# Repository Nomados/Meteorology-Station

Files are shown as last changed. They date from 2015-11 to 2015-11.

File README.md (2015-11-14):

# Meteorology-Station
This device is based on stm32F051 MCU and features measurements of 
temperature, humidity and pressure. It uses sh1106 1.3 OLED display to 
show data and is capable to transfer data via two UARTs if you want to 
organize radio communication. It also has Eagle PCB layout and ready to 
use gerbers (SeedStudio format).

This application uses Chibios/RT RTOS (2.6.x) and uGFX graphics engine.
You should download this software. Place Chibios and uGFX in ../ folder 
of makefile's location. 

For more details please visit:
http://mcudu.blogspot.kr/2015/11/meteorology-station.html

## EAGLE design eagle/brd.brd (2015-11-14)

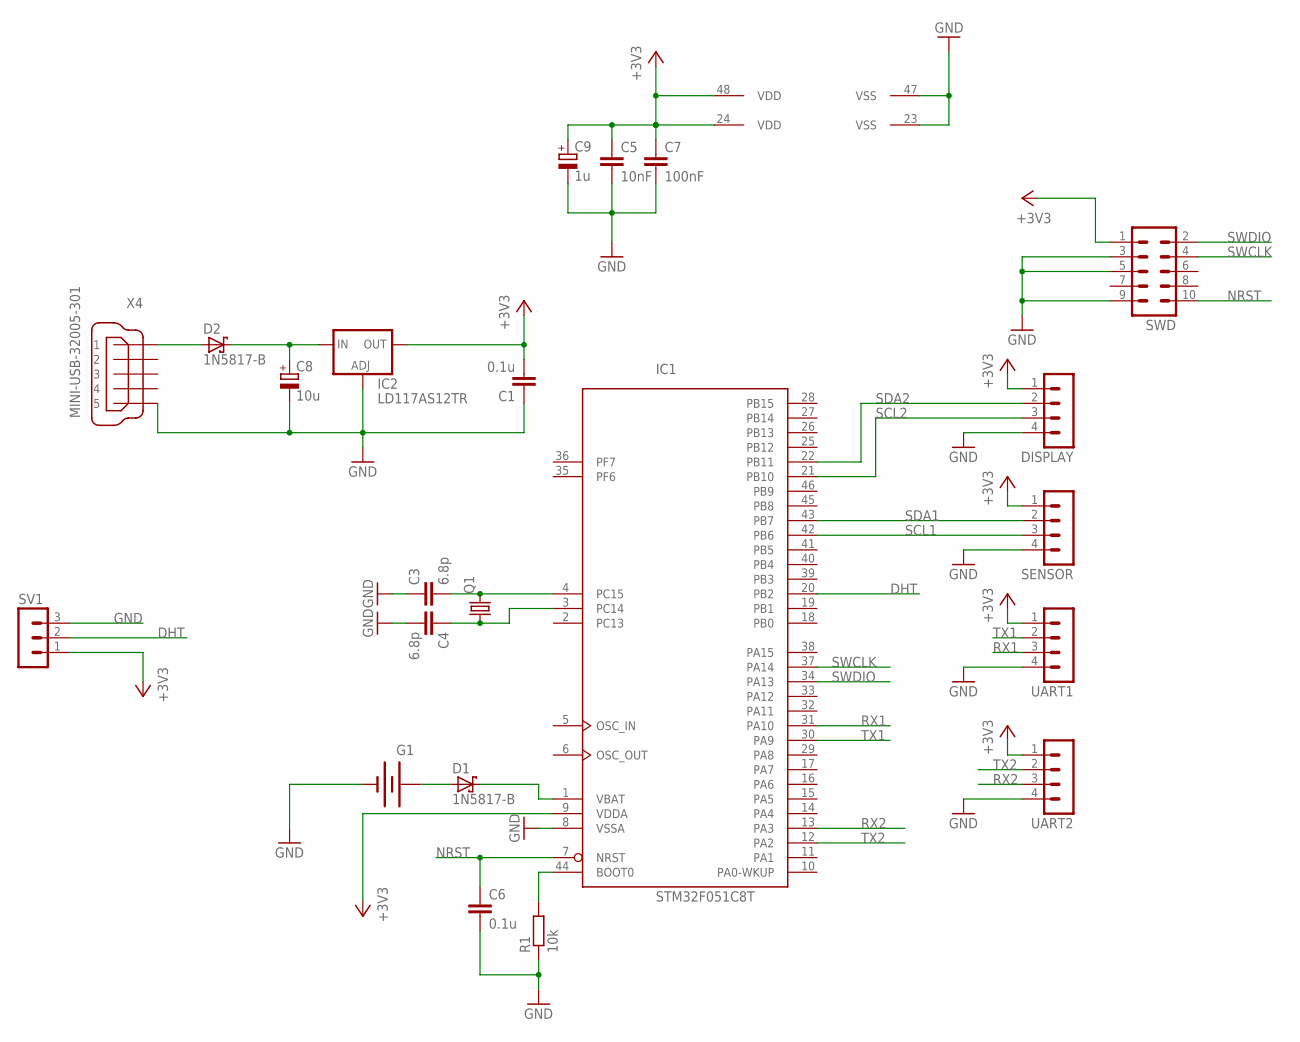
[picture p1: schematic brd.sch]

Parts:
C1: 0.1u; C025-024X044
C3, C4: 6.8p; C0805
C5: 10nF; C0805
C6: 0.1u; C0805
C7: 100nF; C0805
C8: 10u; E2,5-6E
C9: 1u; E2,5-6E
D1, D2: 1N5817-B; DO41-7.6
DISPLAY: MA04-1
G1: BATTERY20PTH; BATTCOM_20MM_PTH
IC1: STM32F051C8T; LQFP48
IC2: LD117AS12TR; SOT223
Q1: CRYSTALTC26H; TC26H
R1: 10k; R0805
SENSOR: MA04-1
SV1: MA03-1
SWD: MA05-2
UART1, UART2: MA04-1
X4: MINI-USB-32005-301; 32005-301

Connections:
+3V3: C1.2, C5.1, C7.1, C9.+, DISPLAY.1, IC1.9 (VDDA), IC1.24 (VDD), IC1.48 (VDD), IC2.4 (OUT), SENSOR.1, SV1.1, SWD.1, UART1.1, UART2.1
DHT: IC1.20 (PB2), SV1.2
GND: C1.1, C3.1, C4.2, C5.2, C6.2, C7.2, C8.-, C9.-, DISPLAY.4, G1.2 (-), IC1.8 (VSSA), IC1.23 (VSS), IC1.47 (VSS), IC2.1 (ADJ), R1.1, SENSOR.4, SV1.3, SWD.3, SWD.5, SWD.9, UART1.4, UART2.4, X4.5
unnamed: C8.+, D2.C, IC2.3 (IN)
unnamed: C3.2, IC1.4 (PC15), Q1.2
unnamed: IC1.44 (BOOT0), R1.2
unnamed: C4.1, IC1.3 (PC14), Q1.1
unnamed: D2.A, X4.1
unnamed: D1.C, IC1.1 (VBAT)
unnamed: D1.A, G1.1 (+)
NRST: C6.1, IC1.7 (NRST), SWD.10
RX1: IC1.31 (PA10), UART1.3
RX2: IC1.13 (PA3), UART2.3
SCL1: IC1.42 (PB6), SENSOR.3
SCL2: DISPLAY.3, IC1.21 (PB10)
SDA1: IC1.43 (PB7), SENSOR.2
SDA2: DISPLAY.2, IC1.22 (PB11)
SWCLK: IC1.37 (PA14), SWD.4
SWDIO: IC1.34 (PA13), SWD.2
TX1: IC1.30 (PA9), UART1.2
TX2: IC1.12 (PA2), UART2.2

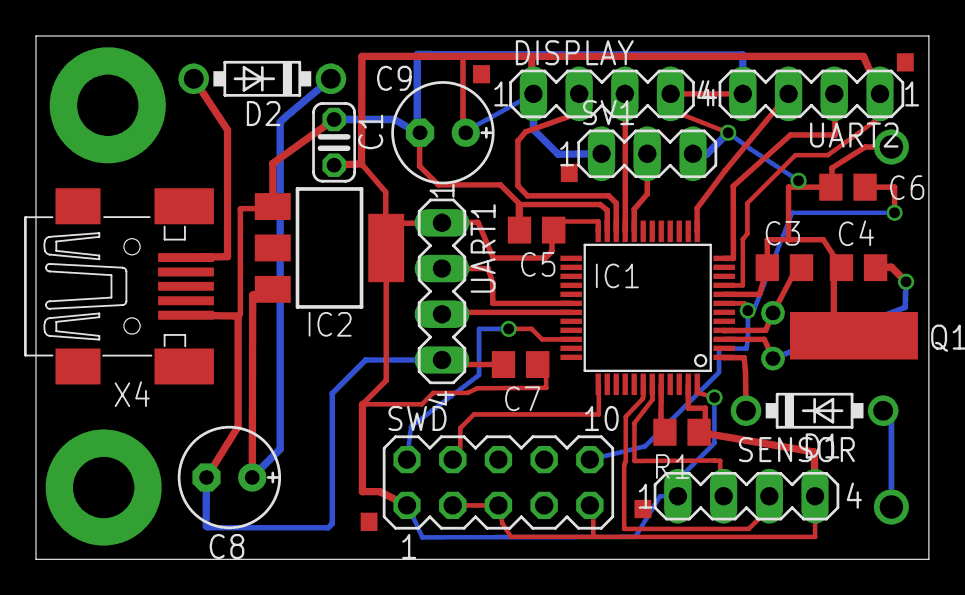
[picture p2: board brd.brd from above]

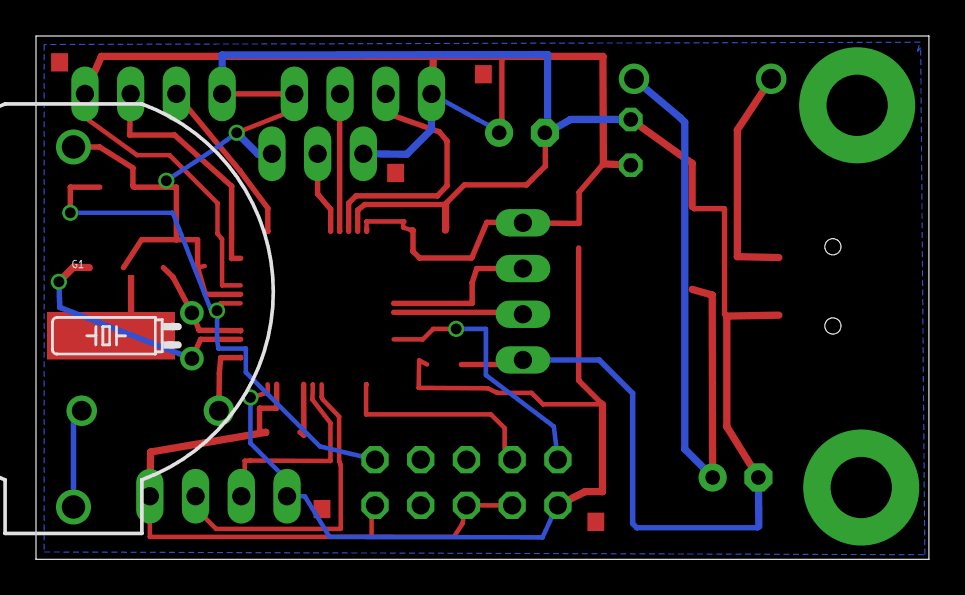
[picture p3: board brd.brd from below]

Board: 2 copper layers, 49.6 x 29.1 mm, 22 parts (2 on the bottom side), 21 nets.

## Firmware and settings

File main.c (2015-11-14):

/*
    ChibiOS/RT - Copyright (C) 2006-2013 Giovanni Di Sirio

    Licensed under the Apache License, Version 2.0 (the "License");
    you may not use this file except in compliance with the License.
    You may obtain a copy of the License at

        http://www.apache.org/licenses/LICENSE-2.0

    Unless required by applicable law or agreed to in writing, software
    distributed under the License is distributed on an "AS IS" BASIS,
    WITHOUT WARRANTIES OR CONDITIONS OF ANY KIND, either express or implied.
    See the License for the specific language governing permissions and
    limitations under the License.
 */

#include "ch.h"
#include "hal.h"
#include "gfx.h"
#include "BarometerData.h"
#include "dht11.h"
#include <string.h>
#include "chprintf.h"




BaroData bd; // baro data structure
static uint8_t dht_buffer[5]; // DHT buffer


I2CConfig i2cconfig =
{
		0x00901D2B,
		0,
		0
};



SerialConfig sc =
{
		19200,
		0,
		0,
		0

};



/* itoa: */
void itoa(int n, char s[])
{

	/* reverse the string */
	void reverse(char s[])
	{
		int i, j;
		char c;

		for (i = 0, j = strlen(s)-1; i<j; i++, j--) {
			c = s[i];
			s[i] = s[j];
			s[j] = c;
		}
	}

	int i, sign;

	if ((sign = n) < 0)
		n = -n;
	i = 0;
	do {
		s[i++] = n % 10 + '0';
	} while ((n /= 10) > 0);
	if (sign < 0)
		s[i++] = '-';
	s[i] = '\0';
	reverse(s);
}





/*
 * OLED thread, times are in milliseconds.
 */
static WORKING_AREA(waOLED, 512);
static msg_t Oled(void *arg)
{
	(void)arg;
	chRegSetThreadName("oled");


	gfxInit();
	font_t font = gdispOpenFont("UI1");
	font_t font1 = gdispOpenFont("UI2");
	gdispSetClip(0, 0, gdispGetWidth(), gdispGetHeight());
	uint8_t x = 7, y = 15;

	while (true)
	{
		char ch[10];
		int temperature = 0;
		int pressure = 0;
		readBarometerData(&bd, 1);
		temperature = (int)bd.TEMP;
		pressure = (int)(bd.PRESSURE * 0.0075);
		int alt = (int)getAltitude(&bd);

		gdispClear(Black);


		gdispDrawString(x, y - 12, "Weather ", font1, White);

		gdispDrawString(x, y, "temperature: ", font, White);
		gdispDrawString(x, y + 12, "pressure: ", font, White);
		gdispDrawString(x, y + 24, "altitude: ", font, White);
		gdispDrawString(x, y + 36, "humidity: ", font, White);



		itoa(temperature, ch);
		gdispDrawString(x+80, y, ch, font, White);

		itoa(pressure, ch);
		gdispDrawString(x+80, y+12, ch, font, White);

		itoa(alt, ch);
		gdispDrawString(x+80, y+24, ch, font, White);



		if (read_DHT11(&dht_buffer[0]) == DHT11_OK)
		{
			itoa(dht_buffer[0], ch);
			gdispDrawString(x+80, y+36, ch, font, White);
			chprintf((BaseSequentialStream*)&SD2, "Temperature: %02dC  pressure: %d kPA  humidity: %02d %%\n\r", temperature, pressure/100, dht_buffer[0]);
		}
		else
		{
			gdispDrawString(x+80, y+36, "Err", font, White);
			chprintf((BaseSequentialStream*)&SD2, "Temperature: %02dC  pressure=%dkPA can't read DHT11 sensor\n\r", temperature, pressure/100);
		}




		gdispGFlush(gdispGetDisplay(0));
		chThdSleepMilliseconds(1000);
	}

	return 0;

}



/*
 * Application entry point.
 */
int main(void)
{
	/*
	 * System initializations.
	 * - HAL initialization, this also initializes the configured device drivers
	 *   and performs the board-specific initializations.
	 * - Kernel initialization, the main() function becomes a thread and the
	 *   RTOS is active.
	 */
	halInit();
	chSysInit();


	/*
	 * Starting the I2C driver 2 for bmp180.
	 */
	i2cStart(&I2CD2, &i2cconfig);
	initialize_bmp180(&bd, 3);
	/*
	 * Activates the serial driver 1 using the driver default configuration.
	 * PA9 and PA10 are routed to USART1 and PA2 and PA3 to USART2
	 */
	sdStart(&SD1, &sc);
	sdStart(&SD2, &sc);

	/*
	 * Creates the threads.
	 */
	//chThdCreateStatic(waDHT11, sizeof(waDHT11), NORMALPRIO - 4, DHT11_Reader, NULL);
	chThdCreateStatic(waOLED, sizeof(waOLED), NORMALPRIO + 1, Oled, NULL);


	while (TRUE)
	{
		chThdSleepMilliseconds(1000);
	}
}

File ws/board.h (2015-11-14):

/*
    ChibiOS/RT - Copyright (C) 2006-2013 Giovanni Di Sirio

    Licensed under the Apache License, Version 2.0 (the "License");
    you may not use this file except in compliance with the License.
    You may obtain a copy of the License at

        http://www.apache.org/licenses/LICENSE-2.0

    Unless required by applicable law or agreed to in writing, software
    distributed under the License is distributed on an "AS IS" BASIS,
    WITHOUT WARRANTIES OR CONDITIONS OF ANY KIND, either express or implied.
    See the License for the specific language governing permissions and
    limitations under the License.
*/

#ifndef _BOARD_H_
#define _BOARD_H_

/*
 * Setup for my meteo board.
 */

/*
 * Board identifier.
 */
#define BOARD_ST_STM32F0_WS
#define BOARD_NAME                  "WeatherStation"

/*
 * Board oscillators-related settings.
 * NOTE: LSE is fitted.
 * NOTE: HSE not fitted.
 */

#define STM32_LSECLK                32768


#define STM32_LSEDRV                (3 << 3)

#if !defined(STM32_HSECLK)
#define STM32_HSECLK                0
#endif




/*
 * MCU type as defined in the ST header.
 */
#define STM32F0XX_MD

/*
 * IO pins assignments.
 */
#define GPIOA_BUTTON                0
#define GPIOA_PIN1                  1
#define GPIOA_PIN2_TX2              2
#define GPIOA_PIN3_RX2              3
#define GPIOA_PIN4                  4
#define GPIOA_PIN5                  5
#define GPIOA_PIN6                  6
#define GPIOA_PIN7                  7
#define GPIOA_PIN8                  8
#define GPIOA_PIN9_TX1              9
#define GPIOA_PIN10_RX1             10
#define GPIOA_PIN11                 11
#define GPIOA_PIN12                 12
#define GPIOA_SWDAT                 13
#define GPIOA_SWCLK                 14
#define GPIOA_PIN15                 15

#define GPIOB_PIN0                  0
#define GPIOB_PIN1                  1
#define GPIOB_PIN2                  2
#define GPIOB_PIN3                  3
#define GPIOB_PIN4                  4
#define GPIOB_PIN5                  5
#define GPIOB_PIN6                  6
#define GPIOB_PIN7                  7
#define GPIOB_PIN8                  8
#define GPIOB_PIN9                  9
#define GPIOB_PIN10_SCL             10
#define GPIOB_PIN11_SDA             11
#define GPIOB_PIN12                 12
#define GPIOB_PIN13                 13
#define GPIOB_PIN14                 14
#define GPIOB_PIN15                 15

#define GPIOC_PIN0                  0
#define GPIOC_PIN1                  1
#define GPIOC_PIN2                  2
#define GPIOC_PIN3                  3
#define GPIOC_PIN4                  4
#define GPIOC_PIN5                  5
#define GPIOC_PIN6                  6
#define GPIOC_PIN7                  7
#define GPIOC_LED4                  8
#define GPIOC_LED3                  9
#define GPIOC_PIN10                 10
#define GPIOC_PIN11                 11
#define GPIOC_PIN12                 12
#define GPIOC_PIN13                 13
#define GPIOC_OSC32_IN              14
#define GPIOC_OSC32_OUT             15

#define GPIOD_PIN0                  0
#define GPIOD_PIN1                  1
#define GPIOD_PIN2                  2
#define GPIOD_PIN3                  3
#define GPIOD_PIN4                  4
#define GPIOD_PIN5                  5
#define GPIOD_PIN6                  6
#define GPIOD_PIN7                  7
#define GPIOD_PIN8                  8
#define GPIOD_PIN9                  9
#define GPIOD_PIN10                 10
#define GPIOD_PIN11                 11
#define GPIOD_PIN12                 12
#define GPIOD_PIN13                 13
#define GPIOD_PIN14                 14
#define GPIOD_PIN15                 15

#define GPIOF_OSC_IN                0
#define GPIOF_OSC_OUT               1
#define GPIOF_PIN2                  2
#define GPIOF_PIN3                  3
#define GPIOF_PIN4                  4
#define GPIOF_PIN5                  5
#define GPIOF_PIN6                  6
#define GPIOF_PIN7                  7
#define GPIOF_PIN8                  8
#define GPIOF_PIN9                  9
#define GPIOF_PIN10                 10
#define GPIOF_PIN11                 11
#define GPIOF_PIN12                 12
#define GPIOF_PIN13                 13
#define GPIOF_PIN14                 14
#define GPIOF_PIN15                 15
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

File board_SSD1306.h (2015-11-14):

/*
 * This file is subject to the terms of the GFX License. If a copy of
 * the license was not distributed with this file, you can obtain one at:
 *
 *              http://ugfx.org/license.html
 */

/**
 * @file    drivers/gdisp/SSD1306/board_SSD1306_i2c.h
 * @brief   GDISP Graphic Driver subsystem board interface for the SSD1306 display.
 */

#ifndef _GDISP_LLD_BOARD_H
#define _GDISP_LLD_BOARD_H

// The command byte to put on the front of each page line
#define SSD1306_PAGE_PREFIX		0x40			 		// Co = 0, D/C = 1
// For a multiple display configuration we would put all this in a structure and then
//	set g->board to that structure.
#define SSD1306_RESET_PORT		GPIOB
#define SSD1306_RESET_PIN		5

//	#define GDISP_SCREEN_WIDTH		132

/**
 * The default slave address is 0x3D, (talking about
 * only the real address part here) and the slave
 * address can be changed to 0x3C by soldering the
 * SA0 pads on the bottom side of the module.
 *
 * b7 | b6 | b5 | b4 | b3 | b2 | b1 | b0
 * --------------------------------------
 * 0  | 1  | 1  | 1  | 1  | 0  |SA0 | R/W
 */
#define SSD1306_I2C_ADDRESS   	0x3C
#define SSD1306_SDA_PORT		GPIOB
#define SSD1306_SDA_PIN			7
#define SSD1306_SCL_PORT		GPIOB
#define SSD1306_SCL_PIN			6
#define SET_RST					palSetPad(SSD1306_RESET_PORT, SSD1306_RESET_PIN);
#define CLR_RST					palClearPad(SSD1306_RESET_PORT, SSD1306_RESET_PIN);

// I2C configuration structure.
static I2CConfig i2cconfig;

#if GFX_USE_OS_CHIBIOS
	static int32_t thdPriority = 0;
#endif

static inline void init_board(GDisplay *g) {

	// As we are not using multiple displays we set g->board to NULL as we don't use it.
	g->board = 0;

	switch(g->controllerdisplay) {
	case 0:											// Set up for Display 0
		// RESET pin.
		palSetPadMode(SSD1306_RESET_PORT, SSD1306_RESET_PIN, PAL_MODE_OUTPUT_PUSHPULL);


		/*
		 * Initializes the I2C driver 1. The I2C1 signals are routed as follows:
		 * PB6 - SCL.
		 * PB7 - SDA.
		 * Timing value comes from ST I2C config tool (xls):
		 * 0x00901D2B;		// 100kHz Standard Mode
		 * 0x00300444;		// 100kHz Fast Mode
		 * 0x0030020A;		// 400kHz Fast Mode
		 * 0x00100002;		// 800kHz Fast Mode +
		 */
		palSetPadMode(SSD1306_SCL_PORT, SSD1306_SCL_PIN, PAL_MODE_ALTERNATE(1));
		palSetPadMode(SSD1306_SDA_PORT, SSD1306_SDA_PIN, PAL_MODE_ALTERNATE(1));
		i2cconfig.timingr = 0x00100002;		// 800kHz Fast Mode+
		i2cInit();
		break;
	}
}

static inline void post_init_board(GDisplay *g) {
	(void) g;
}

static inline void setpin_reset(GDisplay *g, bool_t state) {
	(void) g;
	if(state)
		CLR_RST
	else
		SET_RST
}

static inline void acquire_bus(GDisplay *g) {
	(void) g;
	#if GFX_USE_OS_CHIBIOS
		thdPriority = (int32_t)chThdGetPriority();
		chThdSetPriority(HIGHPRIO);
	#endif
	i2cAcquireBus(&I2CD1);
}

static inline void release_bus(GDisplay *g) {
	(void) g;
	#if GFX_USE_OS_CHIBIOS
		chThdSetPriority(thdPriority);
	#endif
	i2cReleaseBus(&I2CD1);
}

static inline void write_cmd(GDisplay *g, uint8_t cmd) {
	uint8_t command[2];
	(void) g;

	command[0] = 0x00;		// Co = 0, D/C = 0
	command[1] = cmd;

	i2cStart(&I2CD1, &i2cconfig);
	i2cMasterTransmitTimeout(&I2CD1, SSD1306_I2C_ADDRESS, command, 2, NULL, 0, MS2ST(10));
	i2cStop(&I2CD1);
}

static inline void write_data(GDisplay *g, uint8_t* data, uint16_t length) {
	(void) g;

	i2cStart(&I2CD1, &i2cconfig);
	i2cMasterTransmitTimeout(&I2CD1, SSD1306_I2C_ADDRESS, data, length, NULL, 0, MS2ST(10));
	i2cStop(&I2CD1);
}

#endif /* _GDISP_LLD_BOARD_H */

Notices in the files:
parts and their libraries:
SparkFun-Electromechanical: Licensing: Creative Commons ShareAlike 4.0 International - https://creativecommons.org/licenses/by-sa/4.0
